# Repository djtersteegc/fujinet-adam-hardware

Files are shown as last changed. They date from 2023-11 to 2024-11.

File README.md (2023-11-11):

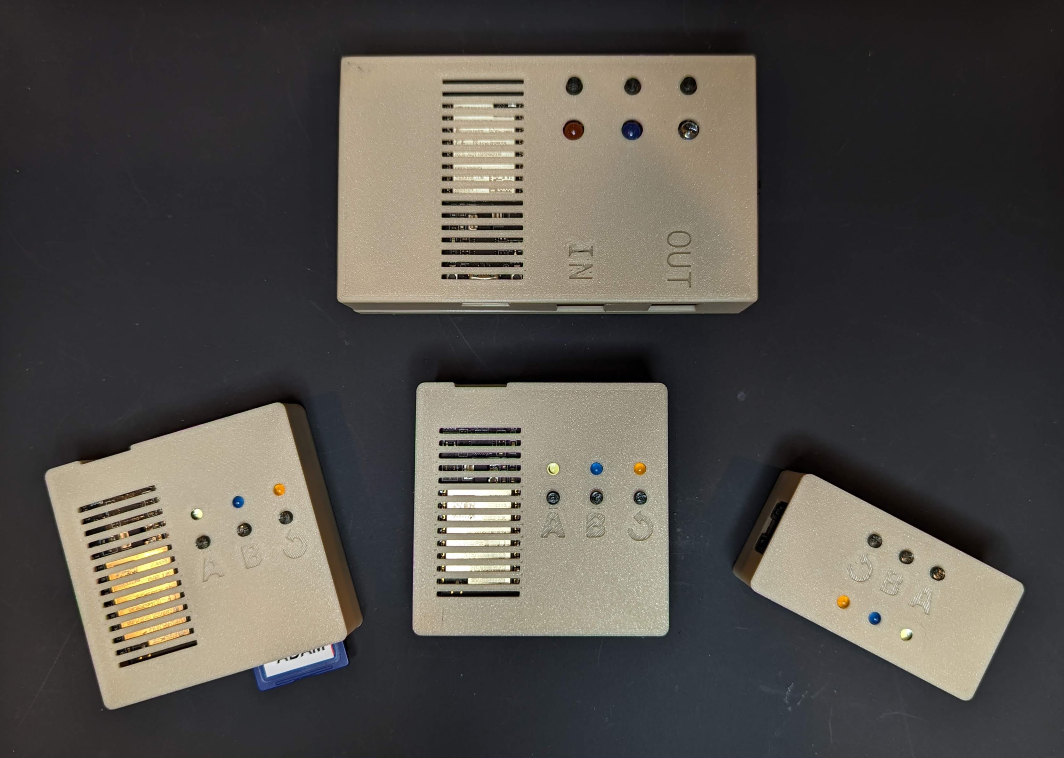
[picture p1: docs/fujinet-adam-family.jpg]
fujinet-adam-family


After building a few of [mozzwald's](https://mozzwald.com/) original [FujiNet](https://fujinet.online/fujinet/) for [Coleco ADAM](https://fujinet.online/fujinet/#ColecoADAM) boards, I decided I wanted to create a new SMD version that was a bit quicker to assemble for folks building them in quantity, but still sticking with the ESP32-Devkit-C-VE board and larger 0805 sized components for the DIY crowd. Both boards are single sided for easy assembly, with the only through hole parts being the RJ12 jack(s), LED's, and the devkit board itself. In the end I ended up with two different designs, one I'm calling the Devkit SMD and the other the Devkit Mini.

# Devkit SMD

Similar to the original design, this one offers two ADAMNet ports to daisy chain other devices, but instead of a microSD slot, now offers a full size SD card.

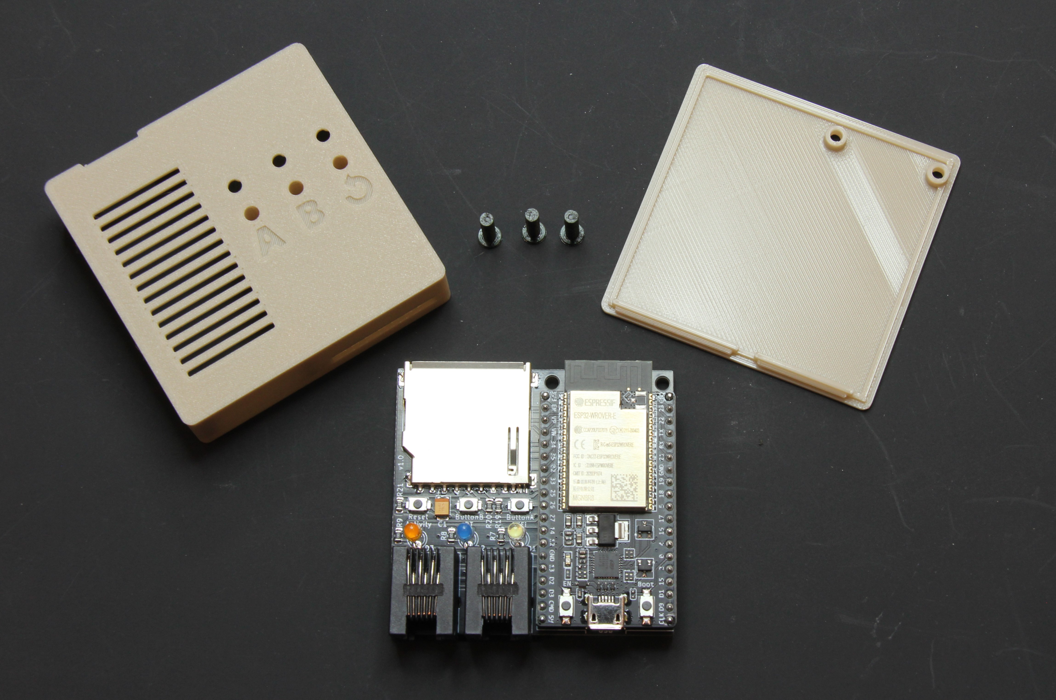
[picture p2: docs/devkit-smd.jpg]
devkit-smd


You can build it in two different configurations, one using 8.5mm female headers for the devkit board, similar to the original.  This gives the options of reusing the ESP32 for something else in the future and easy access to the SMD components underneath it.  If you are confident in your soldering skills and want something more compact, you can also build it with the ESP board soldered directly to the main PCB on 3mm spaces.

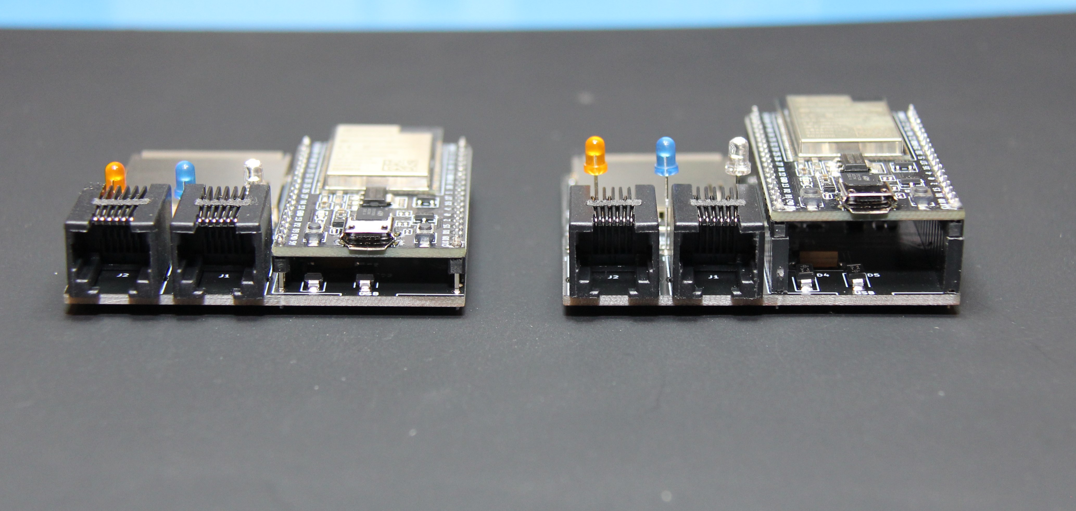
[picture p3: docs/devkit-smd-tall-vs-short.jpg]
devkit-smd-tall-vs-short


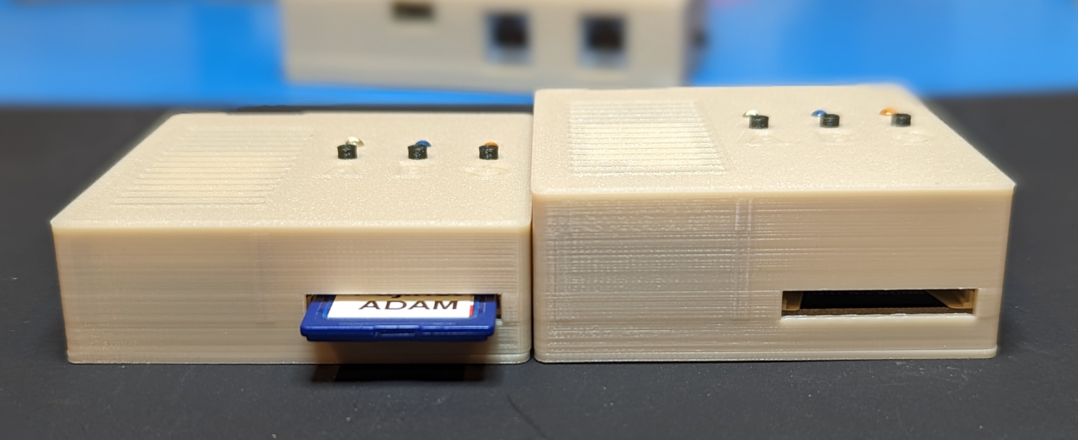
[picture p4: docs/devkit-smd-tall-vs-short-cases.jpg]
devkit-smd-tall-vs-short-cases


See the [Devkit SMD page](fujinet-adam-devkit-smd/README.md) for BOM and assembly instructions.

# Devkit Mini

This was an exercise in can I make a full FujiNet fit in the space of the devkit PCB. For that I had to go back to a microSD slot and it only supports one ADAMNet port.

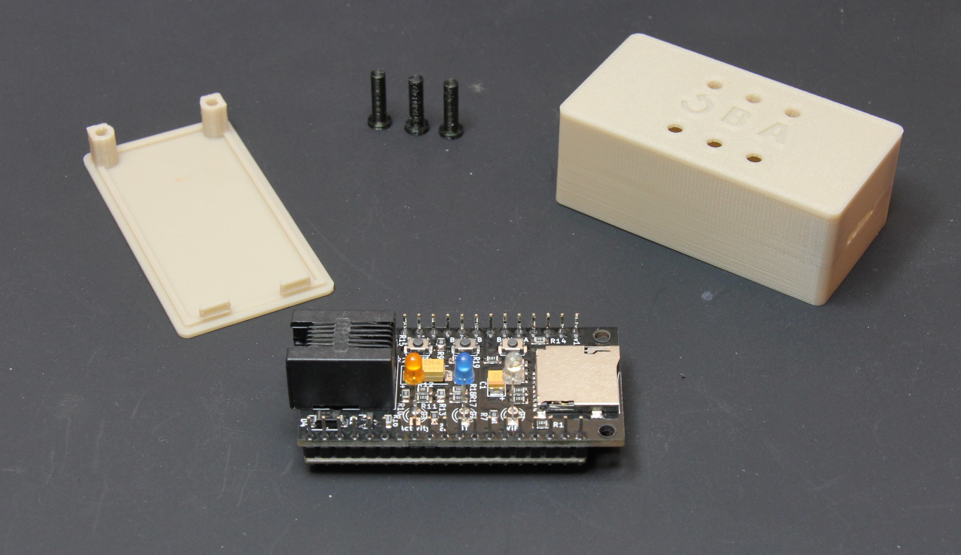
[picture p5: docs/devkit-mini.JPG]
devkit-mini


See the [Devkit Mini page](fujinet-adam-devkit-mini/README.md) for BOM and assembly instructions.

# Getting a Bare Board or Assembled Unit

Any extras I have available will be in my [Tindie](https://www.tindie.com/stores/tersteeg/) store. I don't ship outside the US currently, but gerber files are available for both boards if you want to order your own from your favorite PCB fab like JLCPCB or PCBWay.

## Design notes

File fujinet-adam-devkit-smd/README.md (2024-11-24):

# BOM

There's an interactive BOM [here](https://djtersteegc.github.io/fujinet-adam-hardware/ibom-devkit-smd.html), I find them super useful when placing the SMD parts. 

I buy pretty much everything from AliExpress suppliers with the exception of the tantalum capacitors (whatever is on clearance at Newark) and the ESP32 board (cheaper shipped from Amazon). If you are bulding in the "tall" configuration, you will also need some 2.54mm female headers.  I buy the 1x40p models and break when down into two 19 pin headers required by the devkit board.

C2 is a bulk storage cap for the 5V input from the ADAMNet line.  I speced it at 100uF, but anything from 22uF and up will probably be fine.  You may not even really need it.

C1 is to handle inrush and prevent sag and MCU reboots on the 3.3V rail if you are hot swapping your SD card.  Mozzwald's original design went without, so not strictly needed, especially if you don't plan on hot swapping the card.

| Component | Qty  | Notes | Link |
| --- | ---- | --- | --- |
| 47uF 10V 3528 Tantalum Capacitor | 1 | B Type Case (or smaller) | [AliExpress](https://www.aliexpress.us/item/2251832779546992.html) |
| 100uF 10V 7343 Tantalum Capacitor | 1 | E Type Case (or smaller) | [AliExpress](https://www.aliexpress.us/item/2251832782845246.html) |
| 10K 0805 Resistor | 11 | | [AliExpress](https://www.aliexpress.us/item/3256801607747550.html) |
| 1K 0805 Resistor | 4 | | [AliExpress](https://www.aliexpress.us/item/3256801607747550.html) |
| 2K 0805 Resistor | 2 | | [AliExpress](https://www.aliexpress.us/item/3256801607747550.html) |
| 4.7K 0805 Resistor | 2 | | [AliExpress](https://www.aliexpress.us/item/3256801607747550.html) |
| 1.2K 0805 Resistor | 1 | | [AliExpress](https://www.aliexpress.us/item/3256801607747550.html) |
| 33R 0805 Resistor | 1 | | [AliExpress](https://www.aliexpress.us/item/3256801607747550.html) |
| B140 SMA DO-214 Schottky Diode | 2 | SS14 also works | [AliExpress](https://www.aliexpress.us/item/2255800145156429.html) |
| 3mm LED (Blue) | 1 | Bluetooth | [AliExpress](https://www.aliexpress.us/item/2255800226600744.html) |
| 3mm LED (White) | 1 | Wifi | [AliExpress](https://www.aliexpress.us/item/2255800226600744.html) |
| 3mm LED (Orange) | 1 | Activity | [AliExpress](https://www.aliexpress.us/item/2255800226600744.html) |
| Alps SKRK Style Switch | 3 | 3x4x2mm | [AliExpress](https://www.aliexpress.us/item/2255801131587911.html) |
| MMBT3904 SOT-23 | 1 | | [AliExpress](https://www.aliexpress.us/item/3256802985590487.html) |
| MMBT3906 SOT-23 | 1 | | [AliExpress](https://www.aliexpress.us/item/3256802985563795.html) |
| RJ12 Amphenol 54601 | 2 | 95001-6P6C on Ali | [AliExpress](https://www.aliexpress.us/item/3256802891796239.html) |
| SD Card TE 2041021 | 1 | Long Body on Ali | [AliExpress](https://www.aliexpress.us/item/3256805779248826.html) |
| ESP32-Devkit-C-VE | 1 | | [Amazon](https://www.amazon.com/dp/B087TNPQCV) |
| 2.54mm 19p 8.5mm Tall Female Header | 2 | "Tall" option build only | [AliExpress](https://www.aliexpress.us/item/2251832484668248.html) |
| SK12D07VG4 Slide Switch | 1 | Optional power SW for v1.2 | [AliExpress](https://www.aliexpress.us/item/3256806549741426.html) |

# Flashing

I like to program the ESP32 first to ensure I have a good unit before soldering them onto the main PCB. Since this uses the same devkit board as the "official" model, you can use the FujiNet firmware flasher available at https://fujinet.online/download/. 

# Assembly

Lay down all the SMD components first.  When complete, your board shoud look like this.

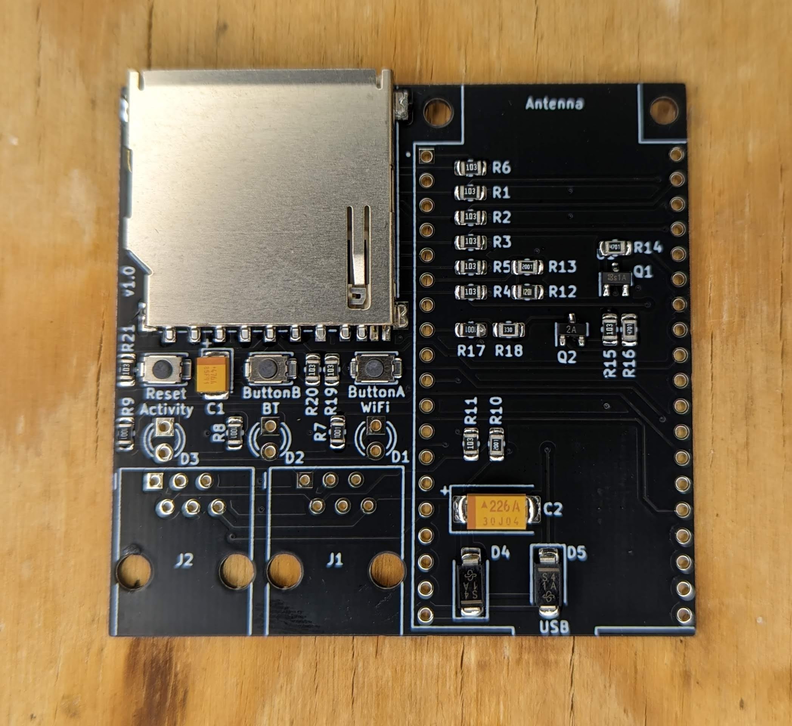
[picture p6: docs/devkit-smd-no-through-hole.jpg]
devkit-smd-no-through-hole


Next decide if you are building it on female headers or soldering the devkit directly to the board.  If the latter, there are some 3mm spacers and support blocks in the "short" 3D directory you can print out to space the devkit board correctly and keep the board level when you flip it over to solder it together.

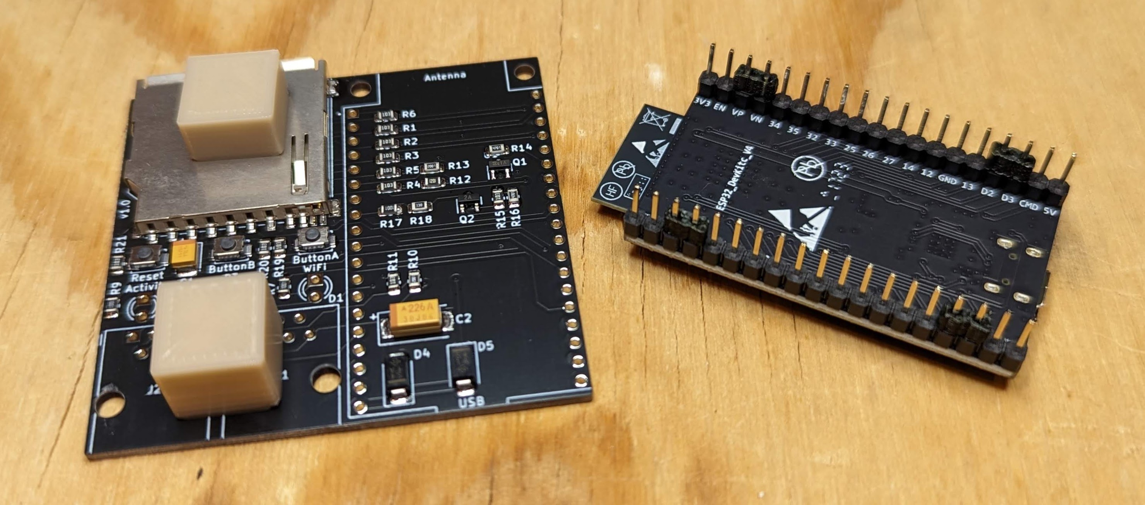
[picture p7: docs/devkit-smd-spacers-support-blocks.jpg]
devkit-smd-spacers-support-blocks


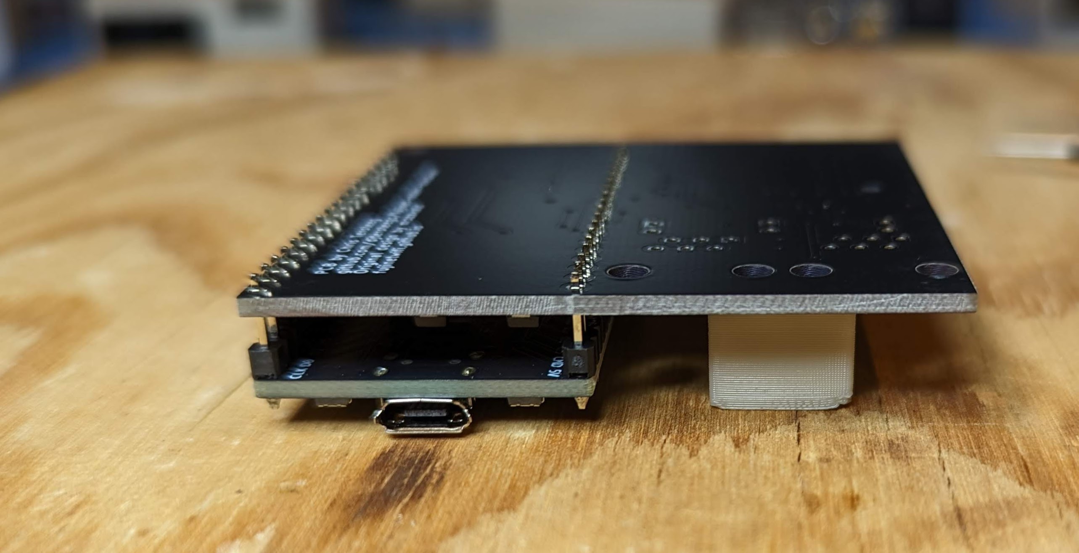
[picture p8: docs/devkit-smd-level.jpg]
devkit-smd-level


Next solder on the two RJ12 jacks.  For the LED's, I first insert them in the PCB, then the PCB in the case, flip it over and support the case ~1mm off the surface for the LED's to just poke through the top and get a nice reveal. Solder one leg on the LED's, flip it over to check your spacing again, and then solder the other leg.

# Case

If built on female headers, print the files in the "tall" directory.  Make sure to print three buttons.  If soldering directly to the board spaced 3mm above it, use the case file in the "short" directory.  Assemble with two M2.5x10mm screws.

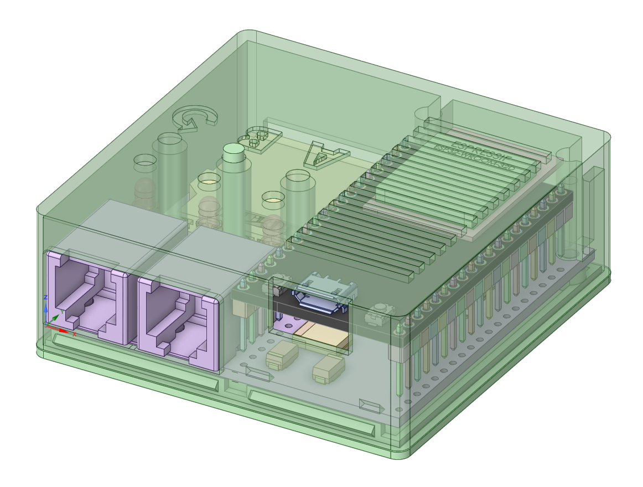
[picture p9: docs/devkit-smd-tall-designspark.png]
devkit-smd-tall-designspark


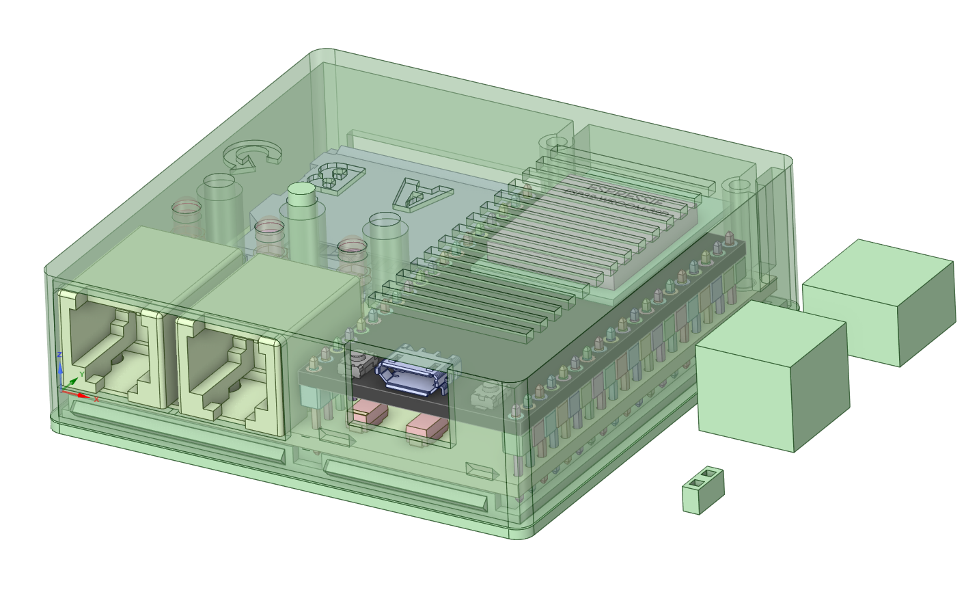
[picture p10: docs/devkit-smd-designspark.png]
devkit-smd-designspark


PCB version 1.2 adds the ability to install a power switch if you want to disable the Fuji in your ADAMNet chain without unplugging it.

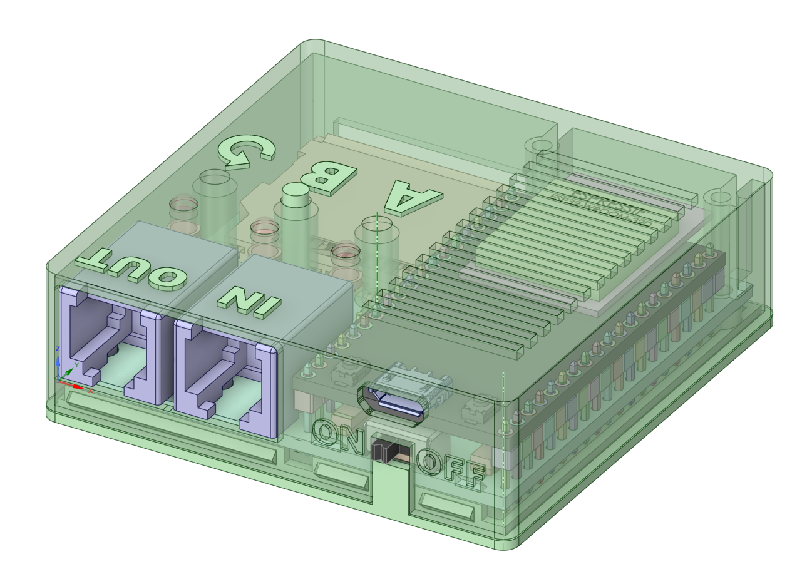
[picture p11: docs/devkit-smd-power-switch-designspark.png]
devkit-smd-power-switch-designspark


If you are printing with a multi color AMS enabled printer, you can use the embossed-text STL files to color fill the top text.

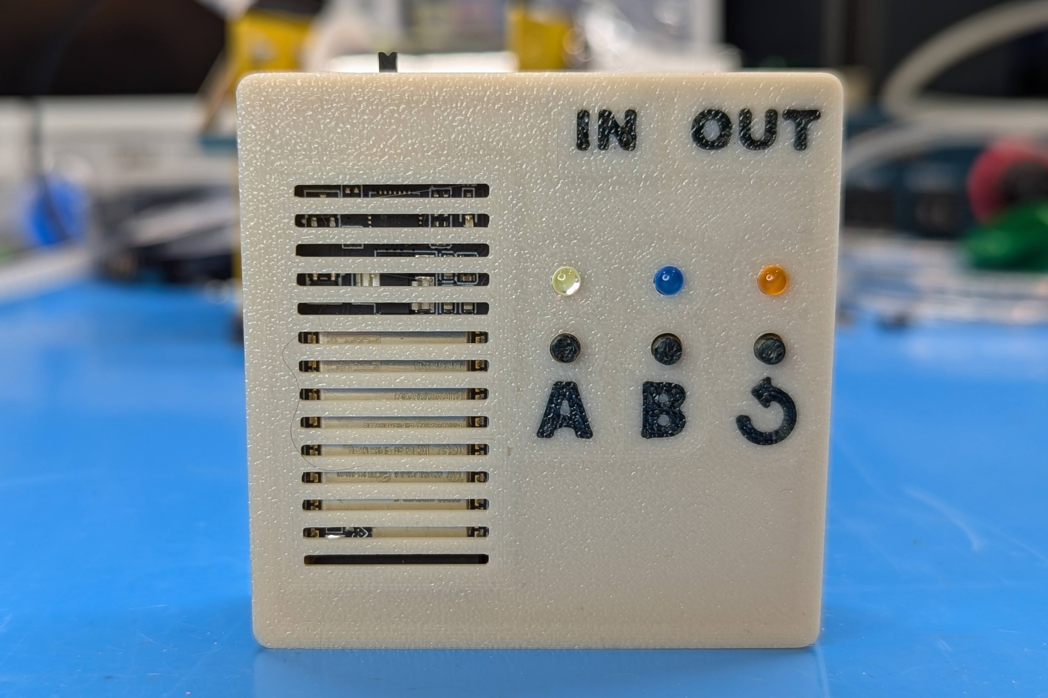
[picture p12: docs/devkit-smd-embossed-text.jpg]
devkit-smd-embossed-text


# PCB Revisions

### Version 1.0

Working, but the second RJ12/ADAMNet connector was incorrectly wired in the schematic and does not work as intended.  I assumed straight through when it should have been reversed, hence the RJ12 cross over cables used on the ADAM. Fortunately, the fix is pretty simple and by luck of the ground planes, you don't even need to remove the RJ12 connector.

These the PCB traces you need to cut (black X's).

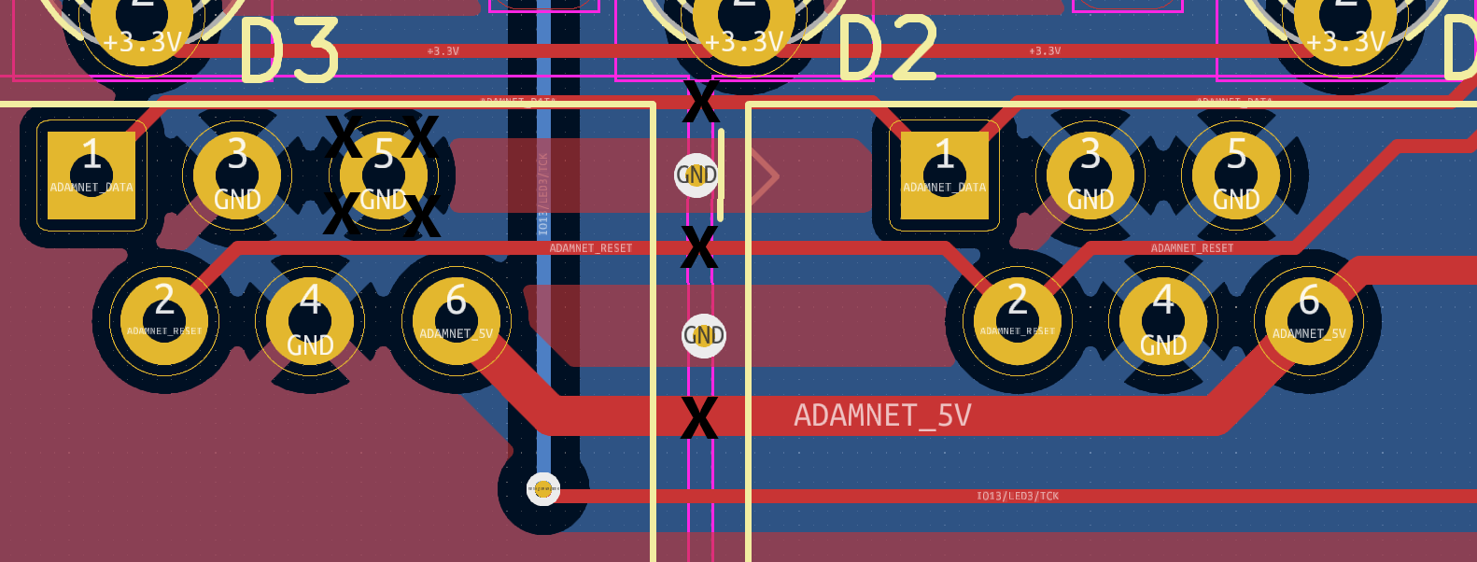
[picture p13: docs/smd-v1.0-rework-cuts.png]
smd-v1.0-rework-cuts


Three are on the top between the two RJ12 jacks.  I used an Xacto blade. Be careful of the trace immediately above the top one connecting the 3.3V rail of the LED's.  I nicked the one in this example, but it was still connected.  Worst case, you need to add another wire to bodge D2 to D3.

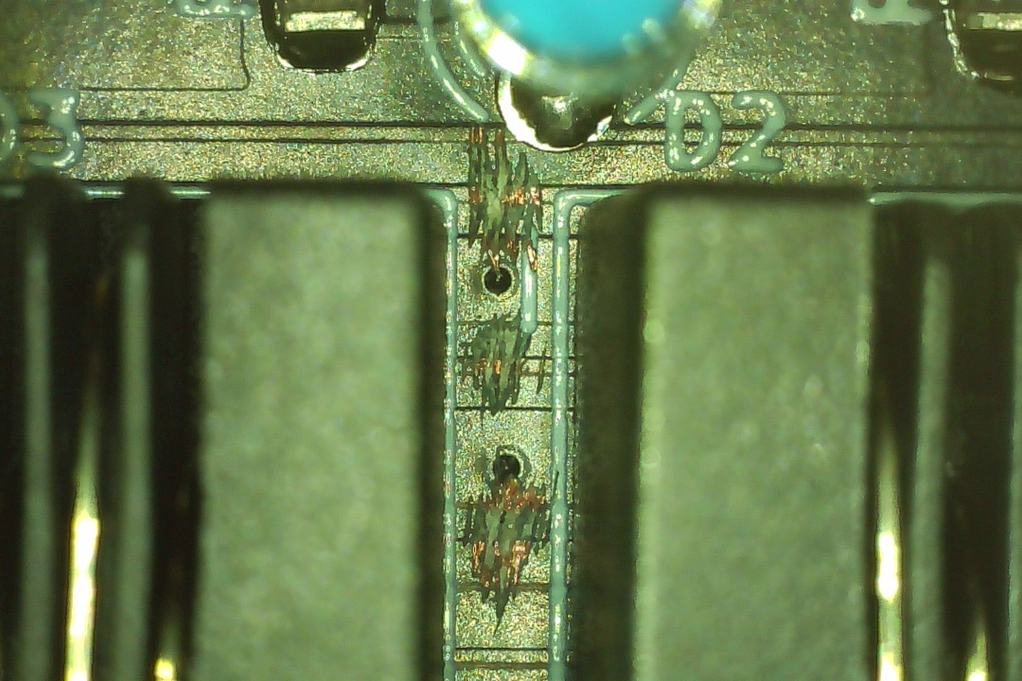
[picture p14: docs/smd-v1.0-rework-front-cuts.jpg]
smd-v1.0-rework-front-cuts


Then you need to seperate the Pin 5 (lower right in the photo) on the back from the four ground plane thermal relief connections.

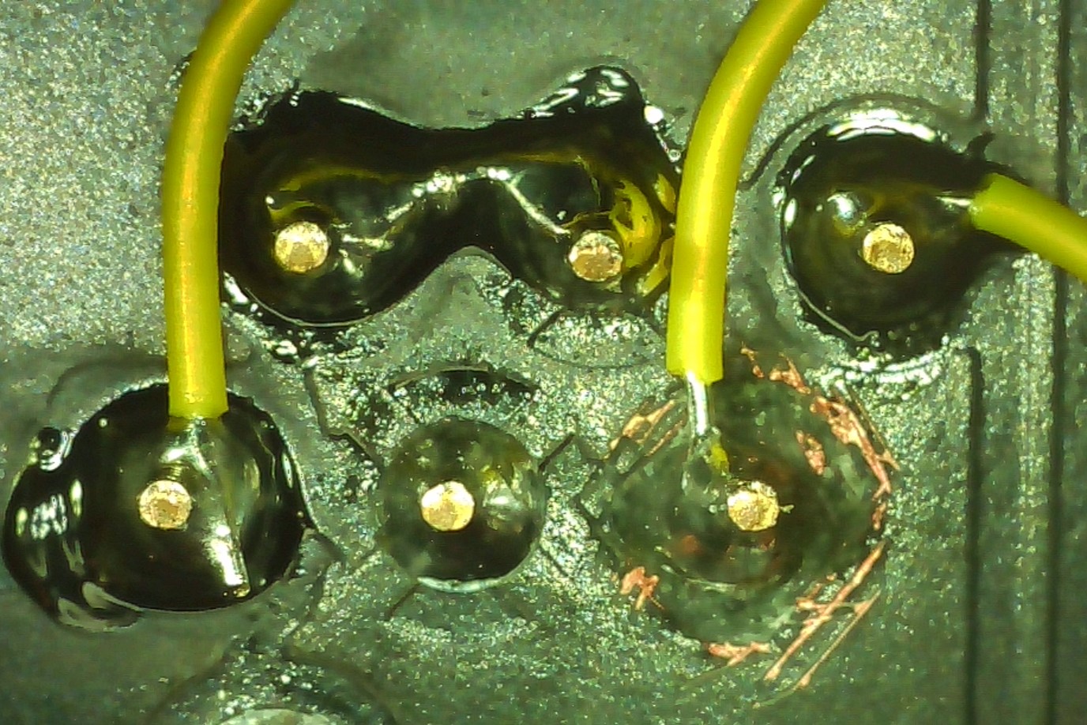
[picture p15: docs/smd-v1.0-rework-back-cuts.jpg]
smd-v1.0-rework-back-cuts


Finally you need to connect J2 to the correct pins on J1. 

| J1 - ADAMNet In | J2 - ADAMNet Out |
| --- | --- |
| 1 (Data) | 6 (Data) |
| 2 (Reset) | 5 (Reset) |
| 3 (GND) | 4 (GND) |
| 4 (GND) | 3 (GND) |
| 5 (GND) | 2 (GND) |
| 6 (5V) | 1 (5V) |

Since pin 3 and pin 4 on J2 are alreay connected to ground nothing to do there.  You can connect Pin 2 which is now GND to Pin 4.  The remaining three pins need bodge wires over to J1.  Here's what it should look like completed.

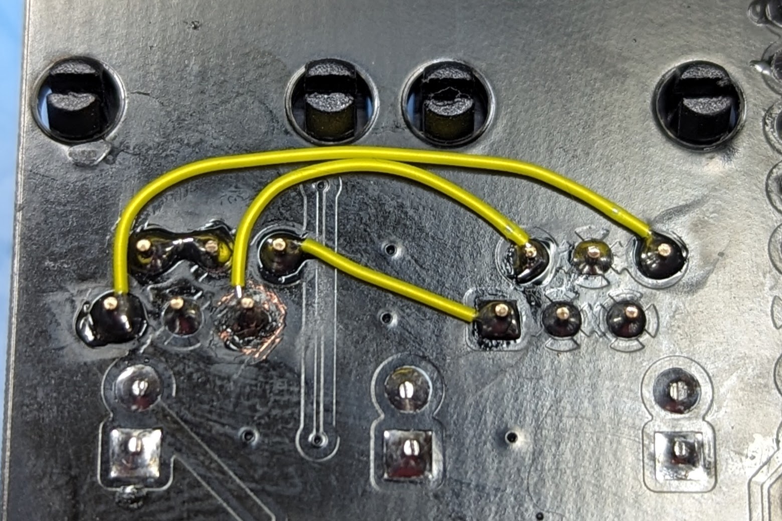
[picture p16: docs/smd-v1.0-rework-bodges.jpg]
smd-v1.0-rework-bodges


Check the connections from J1 to J2 and ensure the 5V line in particular it not shorted to GND.  Plug into the Adam to confirm all is now working with the keyboard plugged into the AdamNET Out (left most) port on the Fujinet.

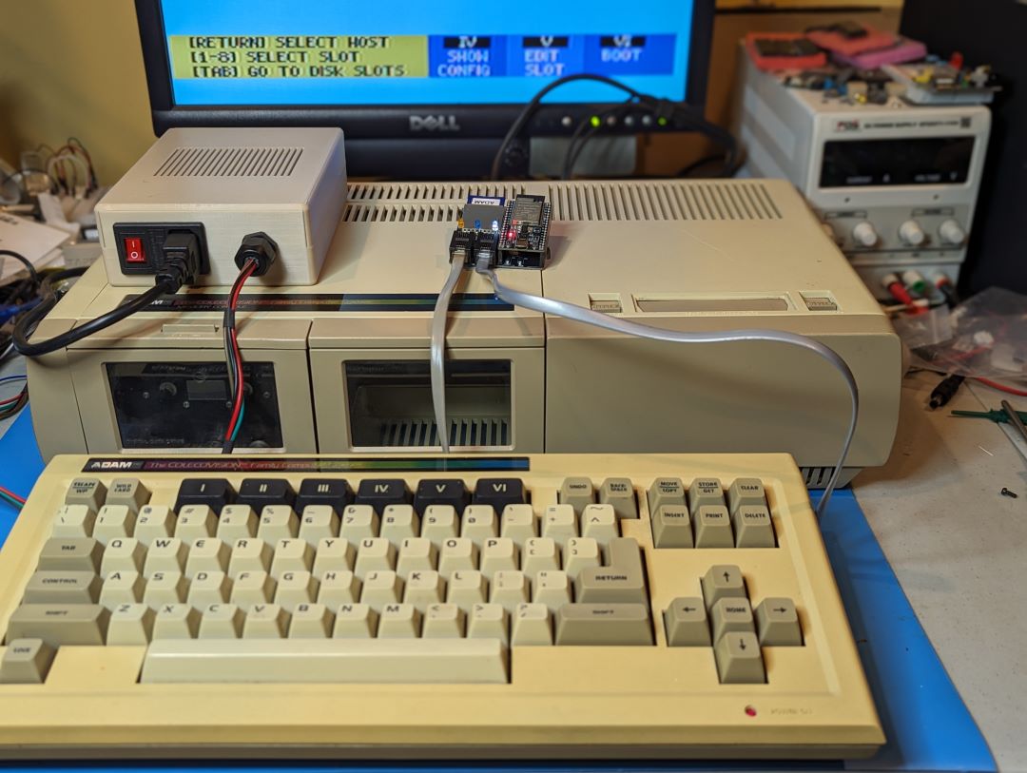
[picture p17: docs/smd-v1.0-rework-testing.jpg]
smd-v1.0-rework-testing


### Version 1.1

All good

### Version 1.2

Adds an optional power switch.  If you don't want to install the swtich, bridge the Always On solder jumper.

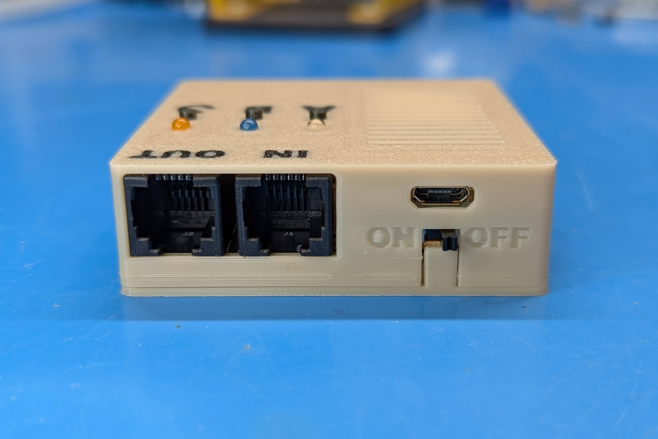
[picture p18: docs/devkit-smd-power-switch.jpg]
devkit-smd-power-switch


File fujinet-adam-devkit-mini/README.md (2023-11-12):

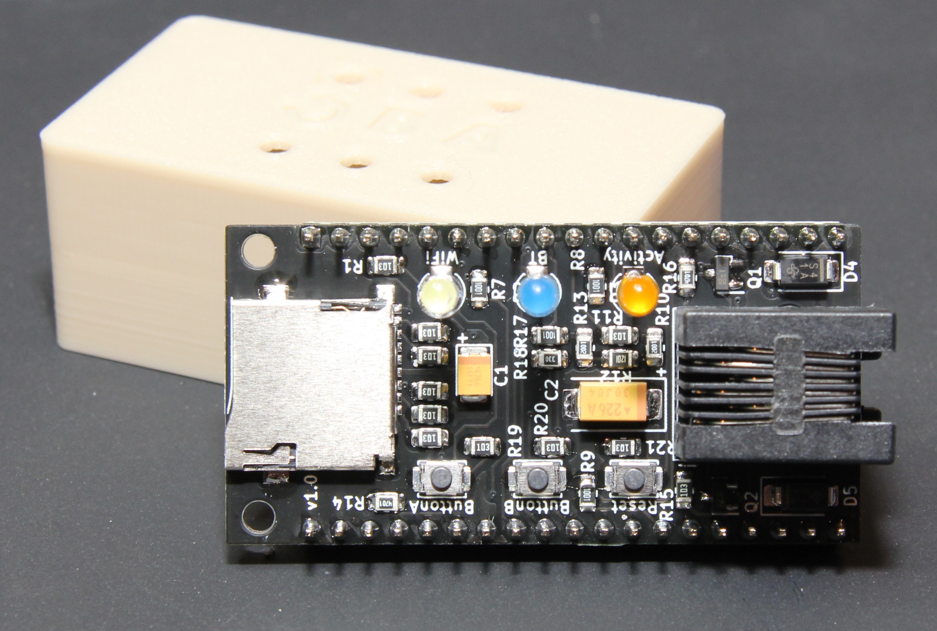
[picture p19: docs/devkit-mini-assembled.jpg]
devkit-mini-assembled


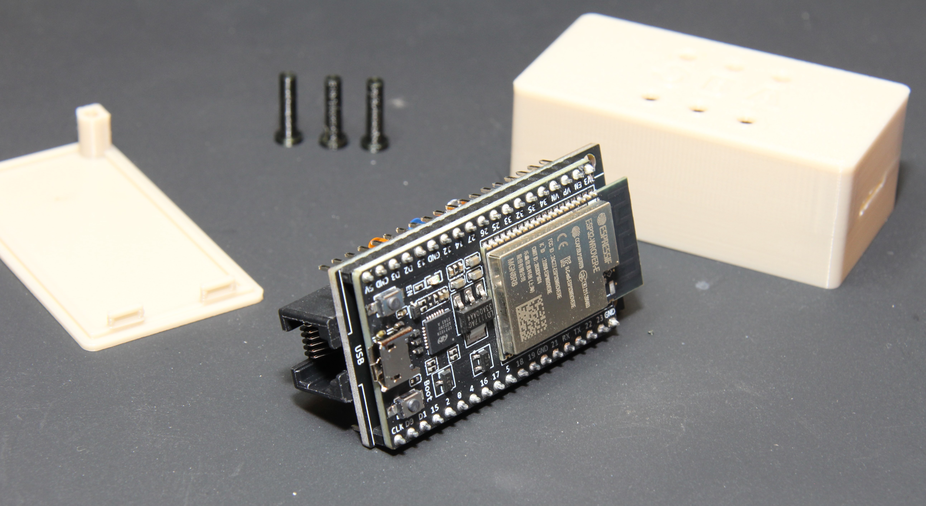
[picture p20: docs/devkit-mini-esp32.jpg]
devkit-mini-esp32


# BOM

There's an interactive BOM [here](https://djtersteegc.github.io/fujinet-adam-hardware/ibom-devkit-mini.html), I find them super useful when placing the SMD parts. 

I buy pretty much everthing from AliExpress suppliers with the exception of the tantalum capacitors (whatever is on clearance at Newark) and the ESP32 board (cheaper shipped from Amazon).

C2 is a bulk storage cap for the 5V input from the ADAMNet line.  I speced it at 100uF, but anything from 22uF and up will probably be fine.  You may not even really need it.

C1 is to handle inrush and prevent sag and MCU reboots on the 3.3V rail if you are hot swapping your SD card.  Mozzwald's original design went without, so not strictly needed, especially if you don't plan on hot swapping the card.

| Component | Qty  | Notes | Link |
| --- | ---- | --- | --- |
| 47uF 10V 3528 Tantalum Capacitor  | 1 | B Type Case (or smaller) | [AliExpress](https://www.aliexpress.us/item/2251832779546992.html) |
| 100uF 10V 7343 Tantalum Capacitor | 1 | E Type Case (or smaller) | [AliExpress](https://www.aliexpress.us/item/2251832782845246.html) |
| 10K 0805 Resistor | 11 | | [AliExpress](https://www.aliexpress.us/item/3256801607747550.html) |
| 1K 0805 Resistor | 4 | | [AliExpress](https://www.aliexpress.us/item/3256801607747550.html) |
| 2K 0805 Resistor | 2 | | [AliExpress](https://www.aliexpress.us/item/3256801607747550.html) |
| 4.7K 0805 Resistor | 2 | | [AliExpress](https://www.aliexpress.us/item/3256801607747550.html) |
| 1.2K 0805 Resistor | 1 | | [AliExpress](https://www.aliexpress.us/item/3256801607747550.html) |
| 33R 0805 Resistor | 1 | | [AliExpress](https://www.aliexpress.us/item/3256801607747550.html) |
| B140 SMA DO-214 Schottky Diode | 2 | SS14 also works | [AliExpress](https://www.aliexpress.us/item/2255800145156429.html) |
| 3mm LED (Blue) | 1 | Bluetooth | [AliExpress](https://www.aliexpress.us/item/2255800226600744.html) |
| 3mm LED (White) | 1 | Wifi | [AliExpress](https://www.aliexpress.us/item/2255800226600744.html) |
| 3mm LED (Orange) | 1 | Activity | [AliExpress](https://www.aliexpress.us/item/2255800226600744.html) |
| Alps SKRK Style Switch | 3 | 3x4x2mm | [AliExpress](https://www.aliexpress.us/item/2255801131587911.html) |
| MMBT3904 SOT-23 | 1 | | [AliExpress](https://www.aliexpress.us/item/3256802985590487.html) |
| MMBT3906 SOT-23 | 1 | | [AliExpress](https://www.aliexpress.us/item/3256802985563795.html) |
| RJ12 Amphenol 54601 | 1 | 95001-6P6C on Ali | [AliExpress](https://www.aliexpress.us/item/3256802891796239.html) |
| microSD Socket | 1 | Push-Push TransFlash on Ali | [AliExpress](https://www.aliexpress.us/item/2251832615736950.html) |
| ESP32-Devkit-C-VE | 1 | | [Amazon](https://www.amazon.com/dp/B087TNPQCV) |

# Flashing

I like to program the ESP32 first to ensure I have a good unit before soldering them onto the main PCB. Since this uses the same devkit board as the "official" model, you can use the FujiNet firmware flasher available at https://fujinet.online/download/. 

# Assembly

Lay down all the SMD components first.

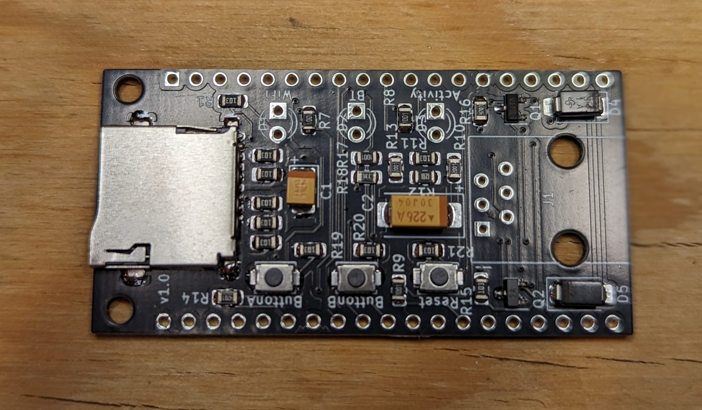
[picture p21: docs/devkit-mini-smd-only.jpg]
devkit-mini-smd-only
 

Next solder on the RJ12 jack.  For the LED's, I first insert them in the PCB, then the PCB in the case, flip it over and support the case ~1mm off the surface (laying the case across the lip of the lid works well for this) for the LED's to just poke through the top and get a nice reveal. Solder one leg on the LED's, flip it over to check your spacing again, and then solder the other leg.

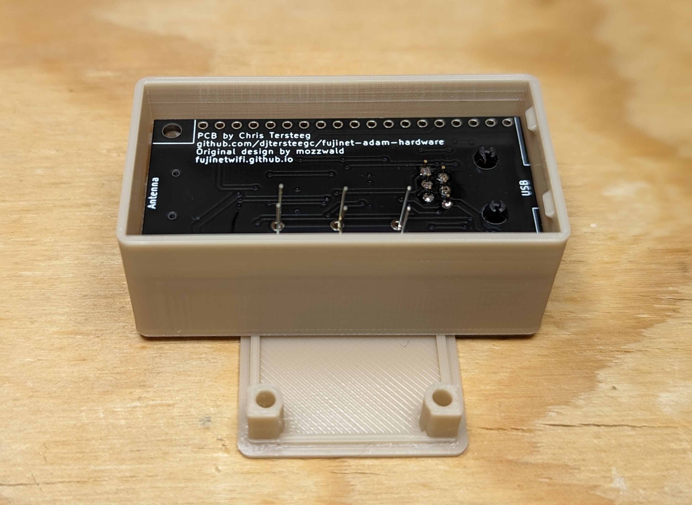
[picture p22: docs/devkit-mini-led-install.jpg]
devkit-mini-led-install


Finally, solder on the devkit board.  I found the cheap PCB/phone vises work well for holding the main PCB while you do this.

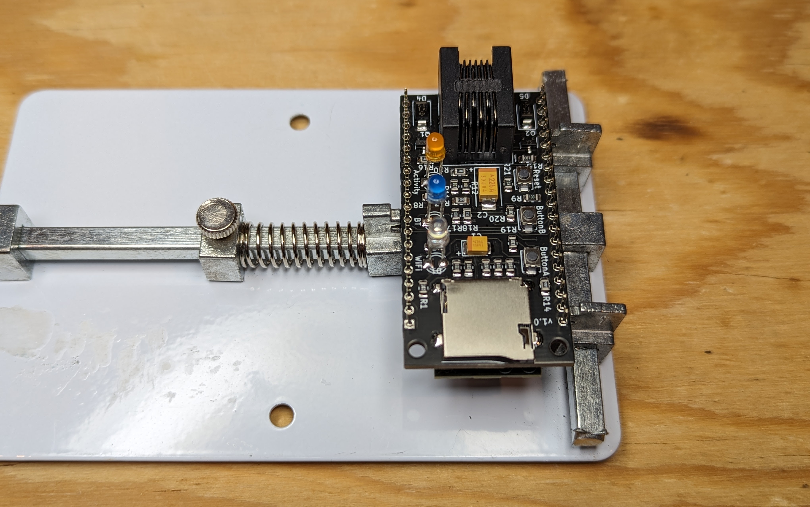
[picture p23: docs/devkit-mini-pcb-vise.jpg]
devkit-mini-pcb-vise


# Case

Make sure to print three buttons.  Assemble with two M2.5x16mm screws.

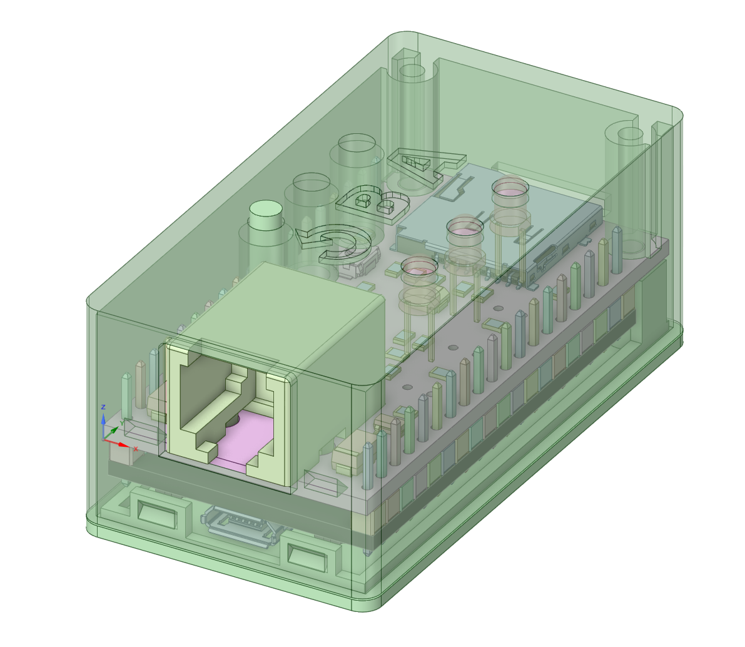
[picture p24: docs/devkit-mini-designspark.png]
devkit-mini-designspark


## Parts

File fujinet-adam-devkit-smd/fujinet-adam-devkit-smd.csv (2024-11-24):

Reference | Value | Datasheet | Footprint | Qty | DNP
C1 | 47uF 10v | ~ | Capacitor_Tantalum_SMD:CP_EIA-3528-15_AVX-H_Pad1.50x2.35mm_HandSolder | 1
C2 | 100uF 10V | ~ | Capacitor_Tantalum_SMD:CP_EIA-7343-20_Kemet-V_Pad2.25x2.55mm_HandSolder | 1
D1 | WIFI_WHITE | ~ | LED_THT:LED_D3.0mm | 1
D2 | BT_BLUE | ~ | LED_THT:LED_D3.0mm | 1
D3 | BUS_ORANGE | ~ | LED_THT:LED_D3.0mm | 1
D4,D5 | B140-E3 | http://www.vishay.com/docs/88946/b120.pdf | Diode_SMD:D_SMA | 2
H1,H2 | MountingHole | ~ | MountingHole:MountingHole_2.7mm_M2.5 | 2
J1 | In | ~ | Connector_RJ:RJ12_Amphenol_54601 | 1
J2 | Out | ~ | Connector_RJ:RJ12_Amphenol_54601 | 1
J3 | SD_Card | http://portal.fciconnect.com/Comergent//fci/drawing/10067847.pdf | Connector_Card:SD_TE_2041021 | 1
JP1 | Always On | ~ | Jumper:SolderJumper-2_P1.3mm_Open_RoundedPad1.0x1.5mm | 1
Q1 | MMBT3904 | https://www.onsemi.com/pdf/datasheet/pzt3904-d.pdf | Package_TO_SOT_SMD:SOT-23 | 1
Q2 | MMBT3906 | https://www.onsemi.com/pdf/datasheet/pzt3906-d.pdf | Package_TO_SOT_SMD:SOT-23 | 1
R1,R2,R3,R4,R5,R6,R11,R15,R19,R20,R21 | 10K | ~ | Resistor_SMD:R_0805_2012Metric_Pad1.20x1.40mm_HandSolder | 11
R7,R8,R9,R17 | 1K | ~ | Resistor_SMD:R_0805_2012Metric_Pad1.20x1.40mm_HandSolder | 4
R10,R13 | 2K | ~ | Resistor_SMD:R_0805_2012Metric_Pad1.20x1.40mm_HandSolder | 2
R12 | 1.2K | ~ | Resistor_SMD:R_0805_2012Metric_Pad1.20x1.40mm_HandSolder | 1
R14,R16 | 4.7K | ~ | Resistor_SMD:R_0805_2012Metric_Pad1.20x1.40mm_HandSolder | 2
R18 | 33R | ~ | Resistor_SMD:R_0805_2012Metric_Pad1.20x1.40mm_HandSolder | 1
S1 | SK12D07VG4 |  | SK12D07VG4:SK12D07VG4 | 1
SW1 | ButtonA | ~ | Button_Switch_SMD:SW_Push_SPST_NO_Alps_SKRK | 1
SW2 | ButtonB | ~ | Button_Switch_SMD:SW_Push_SPST_NO_Alps_SKRK | 1
SW3 | Safe Reset | ~ | Button_Switch_SMD:SW_Push_SPST_NO_Alps_SKRK | 1
U1 | ESP32-DevKitC-VE |  | ESP32-DEVKITC-32U:MODULE_ESP32-DEVKITC-32U | 1

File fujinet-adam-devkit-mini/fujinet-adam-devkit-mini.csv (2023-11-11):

# | Reference | Qty | Value | Footprint | DNP
1 | C1 | 1 | 47uF 10v | Capacitor_Tantalum_SMD:CP_EIA-3528-15_AVX-H_Pad1.50x2.35mm_HandSolder
2 | C2 | 1 | 100uF 10V | Capacitor_Tantalum_SMD:CP_EIA-7343-20_Kemet-V_Pad2.25x2.55mm_HandSolder
3 | D1 | 1 | WIFI_WHITE | LED_THT:LED_D3.0mm
4 | D2 | 1 | BT_BLUE | LED_THT:LED_D3.0mm
5 | D3 | 1 | BUS_ORANGE | LED_THT:LED_D3.0mm
6 | D4, D5 | 2 | B140-E3 | Diode_SMD:D_SMA
7 | H1, H2 | 2 | MountingHole | MountingHole:MountingHole_2.7mm_M2.5
8 | J1 | 1 | RJ12 | Connector_RJ:RJ12_Amphenol_54601
9 | P1 | 1 | ST-TF-003A | ST-TF-003A:SUNTECH_ST-TF-003A
10 | Q1 | 1 | MMBT3904 | Package_TO_SOT_SMD:SOT-23
11 | Q2 | 1 | MMBT3906 | Package_TO_SOT_SMD:SOT-23
12 | R1, R2, R3, R4, R5, R6, R11, R15, R19, R20, R21 | 11 | 10K | Resistor_SMD:R_0805_2012Metric_Pad1.20x1.40mm_HandSolder
13 | R7, R8, R9, R17 | 4 | 1K | Resistor_SMD:R_0805_2012Metric_Pad1.20x1.40mm_HandSolder
14 | R10, R13 | 2 | 2K | Resistor_SMD:R_0805_2012Metric_Pad1.20x1.40mm_HandSolder
15 | R12 | 1 | 1.2K | Resistor_SMD:R_0805_2012Metric_Pad1.20x1.40mm_HandSolder
16 | R14, R16 | 2 | 4.7K | Resistor_SMD:R_0805_2012Metric_Pad1.20x1.40mm_HandSolder
17 | R18 | 1 | 33R | Resistor_SMD:R_0805_2012Metric_Pad1.20x1.40mm_HandSolder
18 | SW1 | 1 | ButtonA | Button_Switch_SMD:SW_Push_SPST_NO_Alps_SKRK
19 | SW2 | 1 | ButtonB | Button_Switch_SMD:SW_Push_SPST_NO_Alps_SKRK
20 | SW3 | 1 | Safe Reset | Button_Switch_SMD:SW_Push_SPST_NO_Alps_SKRK
21 | U1 | 1 | ESP32-DevKitC-VE | ESP32-DEVKITC-32U:MODULE_ESP32-DEVKITC-32U

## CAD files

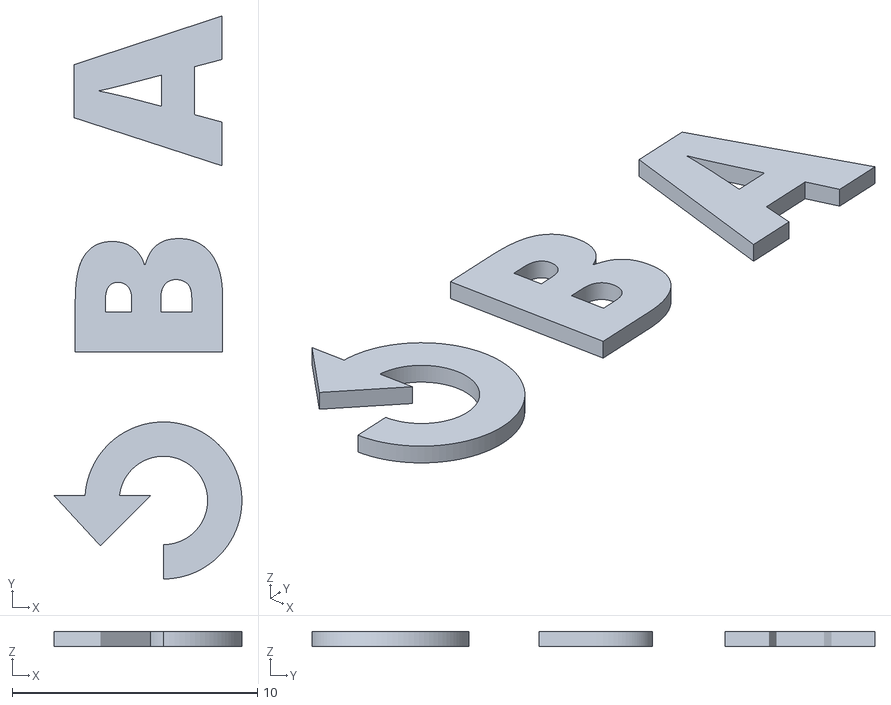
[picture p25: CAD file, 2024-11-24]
fujinet-adam-devkit-mini/3D/fujinet-adam-devkit-mini-embossed-text.stl
7.66 x 22.9 x 0.6

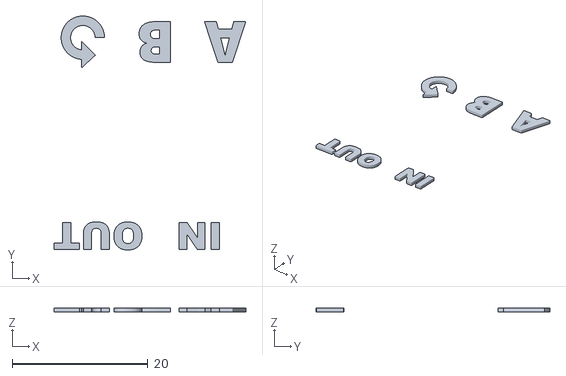
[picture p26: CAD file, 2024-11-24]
fujinet-adam-devkit-smd/3D/short-power-switch/fujinet-adam-devkit-smd-short-power-switch-embossed-text.stl
28.2 x 34.5 x 0.6

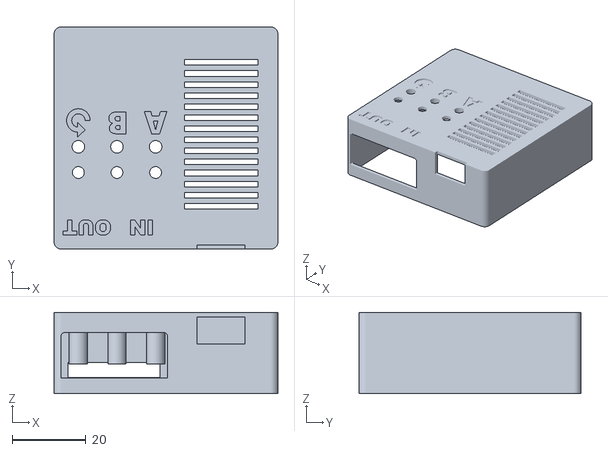
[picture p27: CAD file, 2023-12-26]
fujinet-adam-devkit-smd/3D/tall/fujinet-adam-devkit-smd-case.stl
60.8 x 60.3 x 22.0

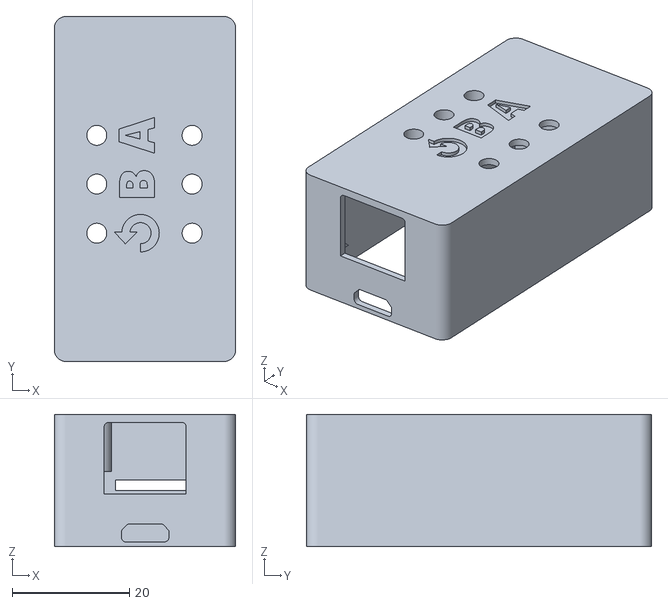
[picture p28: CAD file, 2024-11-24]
fujinet-adam-devkit-mini/3D/fujinet-adam-devkit-mini-body.stl
30.9 x 58.8 x 22.6

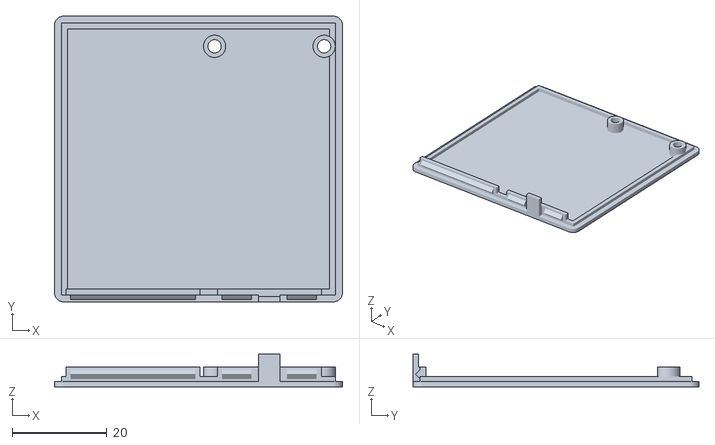
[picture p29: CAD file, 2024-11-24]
fujinet-adam-devkit-smd/3D/short-power-switch/fujinet-adam-devkit-smd-short-power-switch-lid.stl
60.8 x 60.3 x 6.95

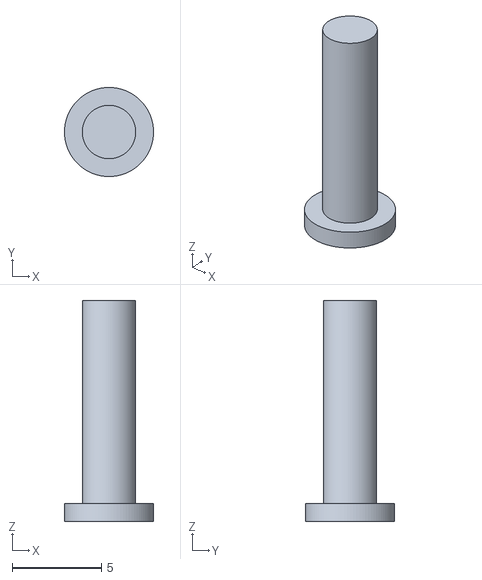
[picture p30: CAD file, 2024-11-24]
fujinet-adam-devkit-smd/3D/short/fujinet-adam-devkit-smd-button.stl
5.00 x 5.00 x 12.4

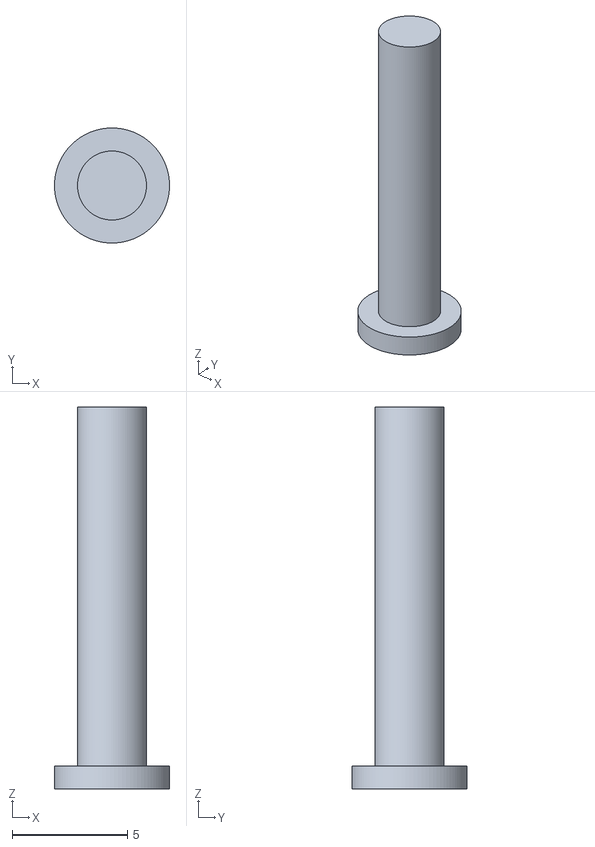
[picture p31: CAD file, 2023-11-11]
fujinet-adam-devkit-smd/3D/tall/fujinet-adam-devkit-smd-button.stl
5.00 x 5.00 x 16.6

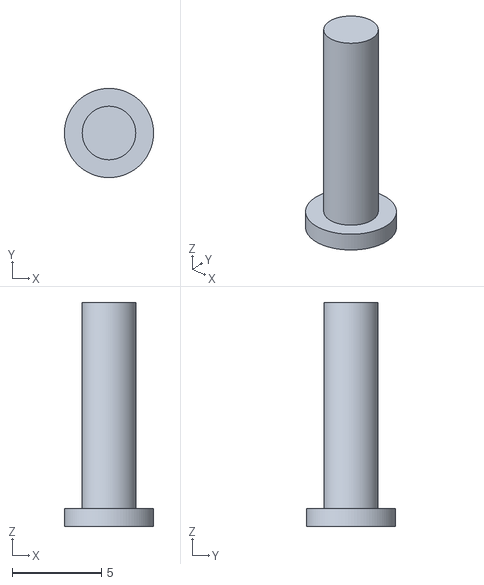
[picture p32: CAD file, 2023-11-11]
fujinet-adam-devkit-mini/3D/fujinet-adam-devkit-mini-button.stl
5.00 x 5.00 x 12.6

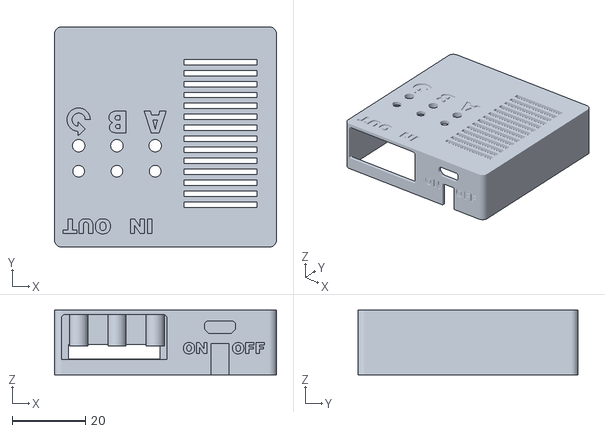
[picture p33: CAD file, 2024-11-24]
fujinet-adam-devkit-smd/3D/short-power-switch/fujinet-adam-devkit-smd-short-power-switch-case.stl
60.8 x 60.3 x 17.8

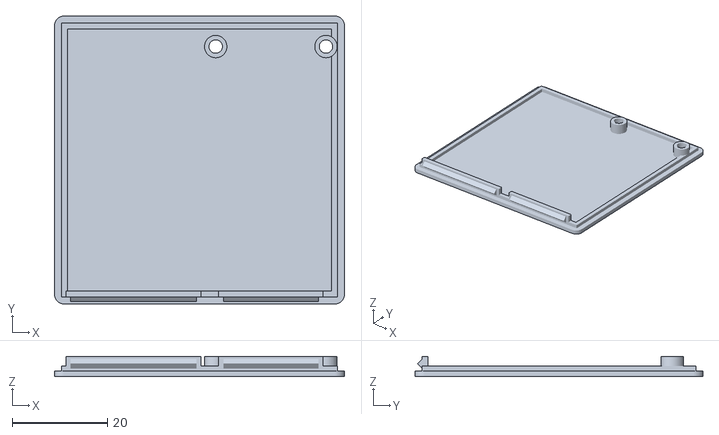
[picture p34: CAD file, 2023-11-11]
fujinet-adam-devkit-smd/3D/tall/fujinet-adam-devkit-smd-lid.stl
60.8 x 60.3 x 4.20

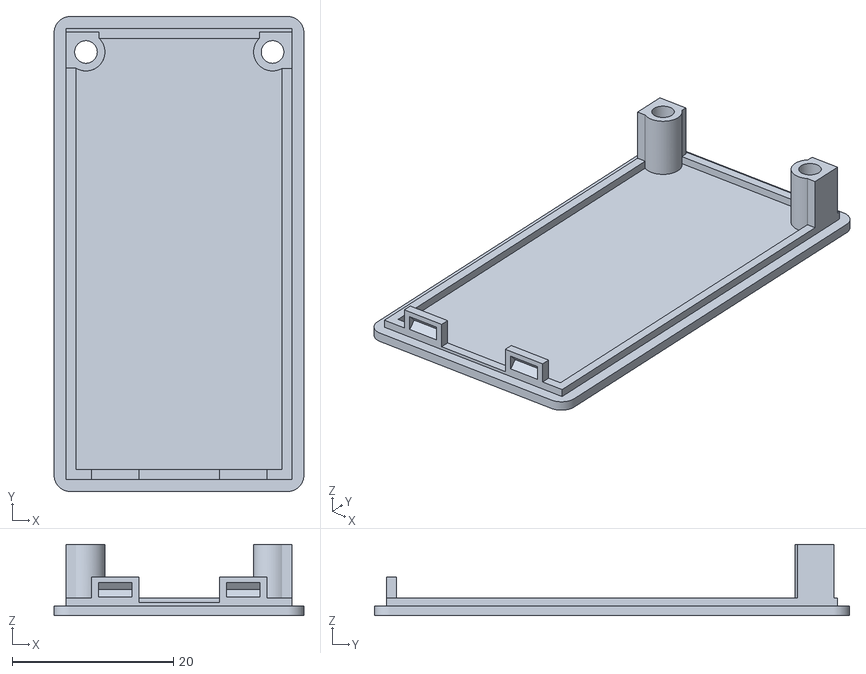
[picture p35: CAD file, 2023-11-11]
fujinet-adam-devkit-mini/3D/fujinet-adam-devkit-mini-lid.stl
30.9 x 58.8 x 8.80

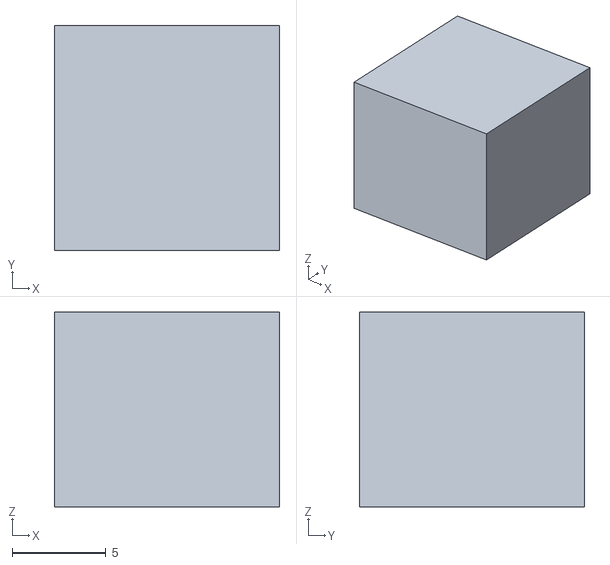
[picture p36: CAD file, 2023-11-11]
fujinet-adam-devkit-smd/3D/short/fujinet-adam-devkit-smd-10.4mm-build-support.stl
12.0 x 12.0 x 10.4

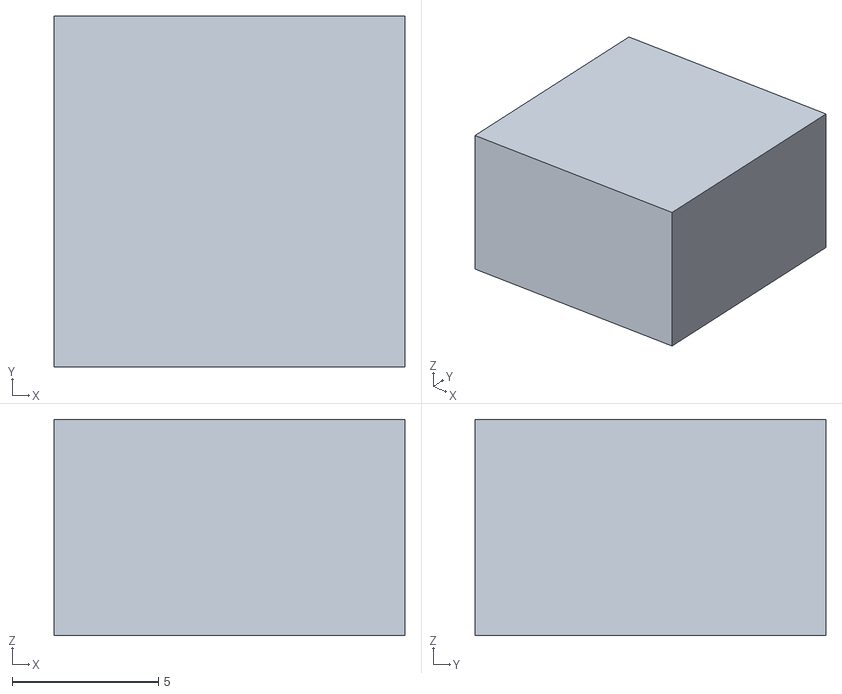
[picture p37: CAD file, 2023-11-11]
fujinet-adam-devkit-smd/3D/short/fujinet-adam-devkit-smd-7.4mm-build-support.stl
12.0 x 12.0 x 7.40

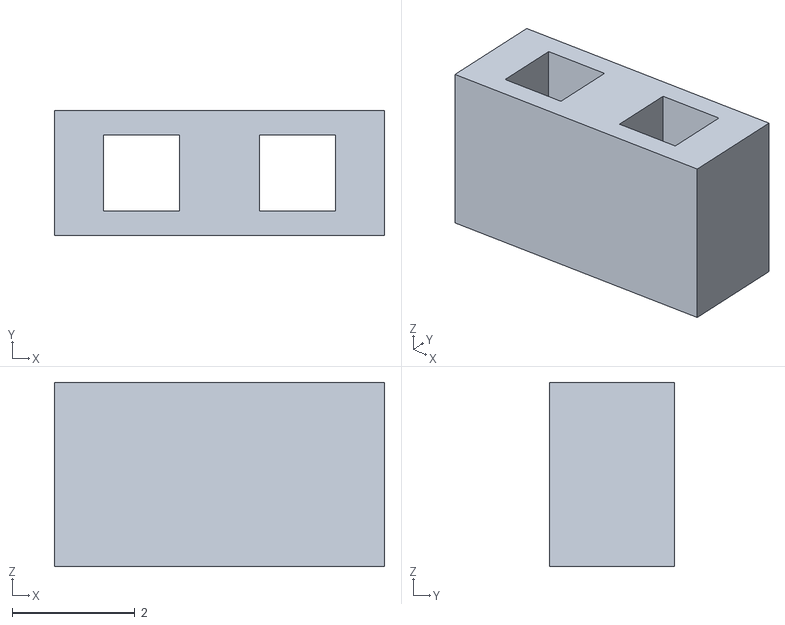
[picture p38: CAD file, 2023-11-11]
fujinet-adam-devkit-smd/3D/short/fujinet-adam-devkit-smd-3mm-spacer.stl
5.38 x 2.04 x 3.00

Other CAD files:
fujinet-adam-devkit-smd/3D/short/fujinet-adam-devkit-smd-embossed-text.stl
fujinet-adam-devkit-smd/3D/short/fujinet-adam-devkit-smd-case.stl
fujinet-adam-devkit-smd/3D/short/fujinet-adam-devkit-smd-lid.stl

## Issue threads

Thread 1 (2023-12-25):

Keyboard conflicts with FujiNet

tingtron, 2023-12-25:
FujiNet and Keyboard connected at the same time have some sort of conflict:
When they keyboard is connected to FujiNet OUT, then

1. There is no keyboard light and keyboard does not type, and
2. Adam-reset always goes to the Typewriter mode, so FujiNet is not activated and only shows an internal red light

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

Separately the keyboard and FujiNet seem to work:
- Fujinet without keyboard, after Adam Reset, boots and shows the Wifi selection screen
- Keyboard by itself is working fine: keyboard light is on, Adam enters Typewriter mode, and types away on the screen.

tingtron, 2023-12-25:
I didn’t find in any guides or videos how exactly FujiNet and the keyboard are connected.
Only in the last [4-hour video](https://youtu.be/P4H7T_FuuqI?si=KzDoaSyd_7JOGv4V&t=1033) I saw that there is another port hidden under on the left side.

But it is still a valid question: how come the pass-through does not work?
Maybe it has to do with the cross over nature of the cable.

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

djtersteegc, 2023-12-26:
Port was incorrectly wired on the schematic.  Added rework instructions for V1.0 here, https://github.com/djtersteegc/fujinet-adam-hardware/tree/main/fujinet-adam-devkit-smd.  Will correct in a V1.1 PCB moving forward.  Will leave issue open until confirm fixed in next PCB revision.

tingtron, 2023-12-26:
So it looks like in V1.0 the connectors were wired parallel, with 2 consequences:
1) it makes no difference which connector is used as input
2) the second cable (Fuji->Keyboard) acted as extension of the first cable (Ada->Fuji). And because they are twisted, twist+twist=straight. But the keyboard requires a twisted cable. Hence no signal or power to the keyboard.

After the rework, one of inputs remains for twisted input, and the other becomes a straight output (like Adam).
Even though V1.0 did not cause any damage switching 5V and signal for FujiNet or Keyboard, it may cause issues with other equipment, e.g. if its signal connected to ground.

So it would be extremely helpful to indicate the IN and OUT ports on the case

djtersteegc, 2024-01-03:
Yep, case was also updated with the v1.1 PCB commits.

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

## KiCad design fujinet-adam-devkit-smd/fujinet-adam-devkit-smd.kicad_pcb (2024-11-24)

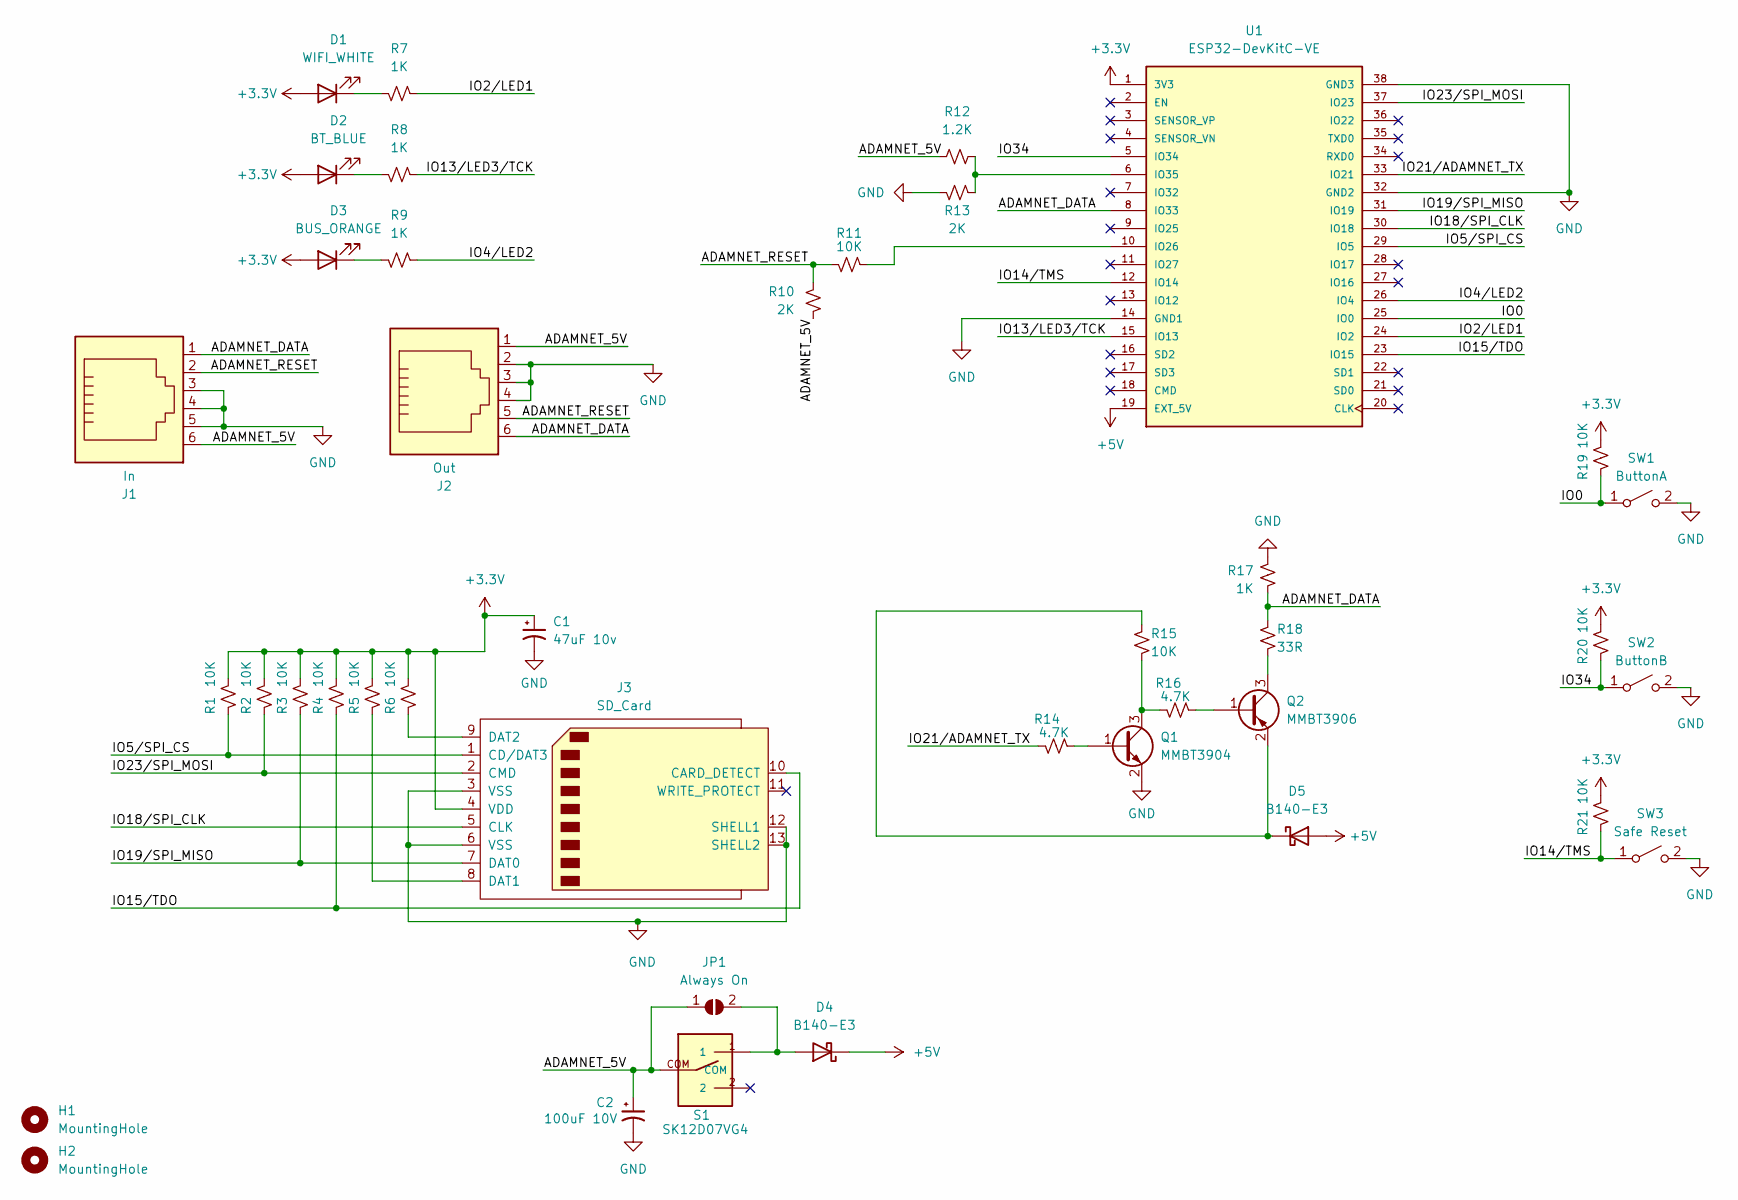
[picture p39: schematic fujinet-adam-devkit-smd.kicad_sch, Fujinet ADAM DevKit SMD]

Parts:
C1: 47uF 10v; CP_EIA-3528-15_AVX-H_Pad1.50x2.35mm_HandSolder
C2: 100uF 10V; CP_EIA-7343-20_Kemet-V_Pad2.25x2.55mm_HandSolder
D1: WIFI_WHITE; LED_D3.0mm
D2: BT_BLUE; LED_D3.0mm
D3: BUS_ORANGE; LED_D3.0mm
D4, D5: B140-E3; D_SMA
H1, H2: MountingHole; MountingHole_2.7mm_M2.5
J1: In; RJ12_Amphenol_54601
J2: Out; RJ12_Amphenol_54601
J3: SD_Card; SD_TE_2041021
JP1: Always On; SolderJumper-2_P1.3mm_Open_RoundedPad1.0x1.5mm
Q1: MMBT3904; SOT-23
Q2: MMBT3906; SOT-23
R1, R2, R3, R4, R5, R6, R11, R15, R19, R20, R21: 10K; R_0805_2012Metric_Pad1.20x1.40mm_HandSolder
R7, R8, R9, R17: 1K; R_0805_2012Metric_Pad1.20x1.40mm_HandSolder
R10, R13: 2K; R_0805_2012Metric_Pad1.20x1.40mm_HandSolder
R12: 1.2K; R_0805_2012Metric_Pad1.20x1.40mm_HandSolder
R14, R16: 4.7K; R_0805_2012Metric_Pad1.20x1.40mm_HandSolder
R18: 33R; R_0805_2012Metric_Pad1.20x1.40mm_HandSolder
S1: SK12D07VG4
SW1: ButtonA; SW_Push_SPST_NO_Alps_SKRK
SW2: ButtonB; SW_Push_SPST_NO_Alps_SKRK
SW3: Safe Reset; SW_Push_SPST_NO_Alps_SKRK
U1: ESP32-DevKitC-VE; MODULE_ESP32-DEVKITC-32U; PARTREV N/A

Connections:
+3.3V: C1.1, D1.2 (A), D2.2 (A), D3.2 (A), J3.4 (VDD), R1.2, R2.2, R3.2, R4.2, R5.2, R6.2, R19.2, R20.2, R21.2, U1.1 (3V3)
+5V: D4.1 (K), D5.2 (A), U1.19 (EXT_5V)
/ADAMNET_5V: C2.1, J1.6, J2.1, JP1.1 (A), R10.1, R12.1, S1.COM
/ADAMNET_DATA: J1.1, J2.6, R17.1, R18.2, U1.8 (IO33)
/ADAMNET_RESET: J1.2, J2.5, R10.2, R11.1
/IO0: R19.1, SW1.1 (A), U1.25 (IO0)
/IO2/LED1: R7.2, U1.24 (IO2)
/IO4/LED2: R9.2, U1.26 (IO4)
/IO5/SPI_CS: J3.1 (CD/DAT3), R1.1, U1.29 (IO5)
/IO13/LED3/TCK: R8.2, U1.15 (IO13)
/IO14/TMS: R21.1, SW3.1 (A), U1.12 (IO14)
/IO15/TDO: J3.10 (CARD_DETECT), R4.1, U1.23 (IO15)
/IO18/SPI_CLK: J3.5 (CLK), U1.30 (IO18)
/IO19/SPI_MISO: J3.7 (DAT0), R3.1, U1.31 (IO19)
/IO21/ADAMNET_TX: R14.2, U1.33 (IO21)
/IO23/SPI_MOSI: J3.2 (CMD), R2.1, U1.37 (IO23)
/IO34: R20.1, SW2.1 (A), U1.5 (IO34)
GND: C1.2, C2.2, J1.3, J1.4, J1.5, J2.2, J2.3, J2.4, J3.3 (VSS), J3.6 (VSS), J3.12 (SHELL1), J3.13 (SHELL2), Q1.2 (E), R13.1, R17.2, SW1.2 (B), SW2.2 (B), SW3.2 (B), U1.14 (GND1), U1.32 (GND2), U1.38 (GND3)
unnamed: D1.1 (K), R7.1
unnamed: D2.1 (K), R8.1
unnamed: D3.1 (K), R9.1
unnamed: D4.2 (A), JP1.2 (B), S1.1
unnamed: D5.1 (K), Q2.2 (E), R15.2
unnamed: J3.8 (DAT1), R5.1
unnamed: J3.9 (DAT2), R6.1
unnamed: Q1.1 (B), R14.1
unnamed: Q1.3 (C), R15.1, R16.2
unnamed: Q2.1 (B), R16.1
unnamed: Q2.3 (C), R18.1
unnamed: R11.2, U1.10 (IO26)
unnamed: R12.2, R13.2, U1.6 (IO35)

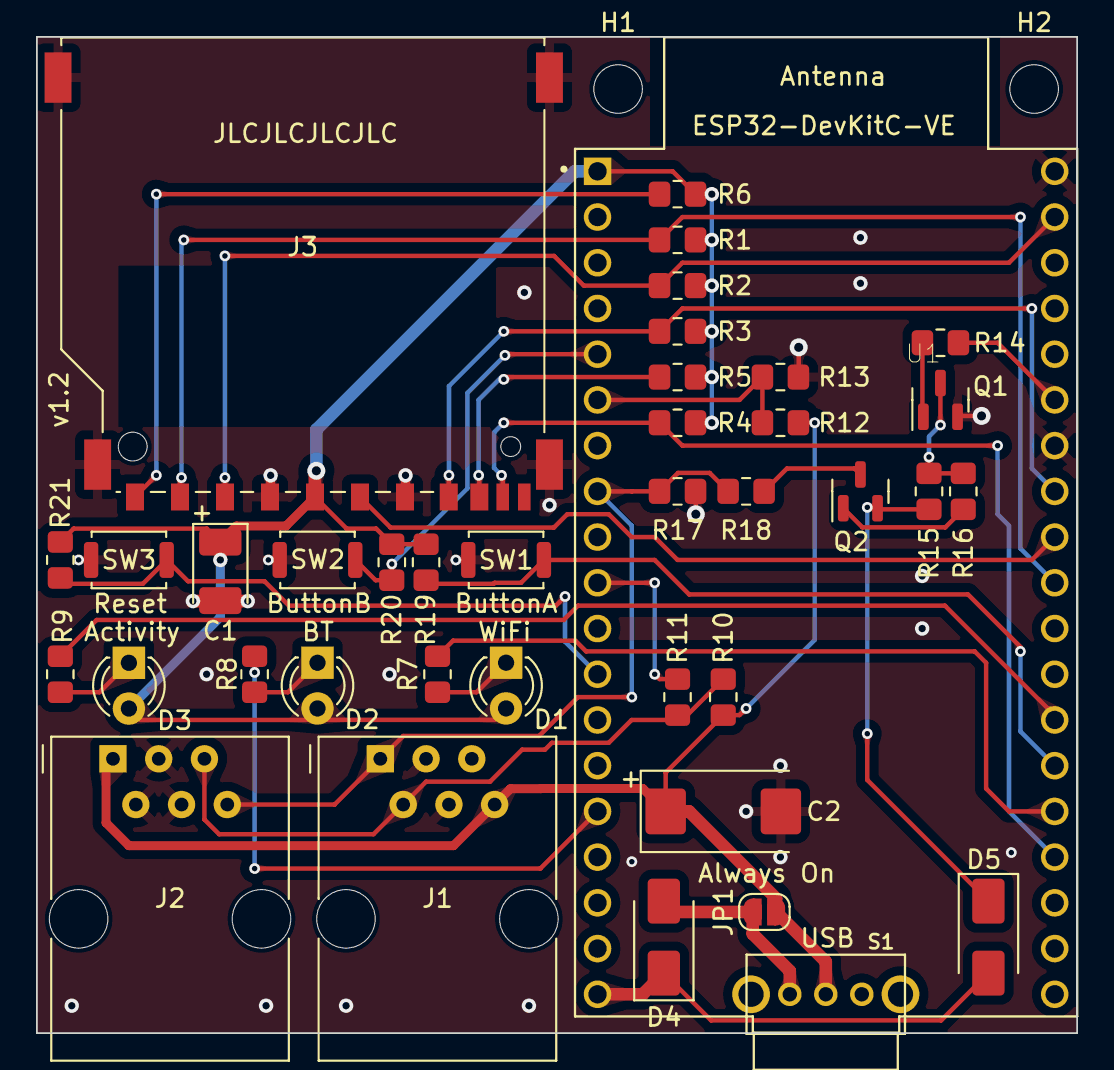
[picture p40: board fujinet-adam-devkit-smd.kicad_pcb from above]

Board: 2 copper layers, 57.8 x 55.3 mm, 41 parts (0 on the bottom side), 31 nets.

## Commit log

2023-11-11 Add some docs
    [fujinet-adam-devkit-mini-body.stl, fujinet-adam-devkit-mini-button.stl, fujinet-adam-devkit-mini-lid.stl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]
2023-11-11 Update docs
    [fujinet-adam-devkit-mini.csv, fujinet-adam-devkit-mini.kicad_pcb, fujinet-adam-devkit-mini.kicad_sch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]
2023-11-12 Fix Mini BOM in README
2023-12-25 Add rework cut pic
2023-12-26 Update SMD PCB and Case to v1.1, fix ADAMNet Out port not working
    [fujinet-adam-devkit-smd-B_Cu.gbr, fujinet-adam-devkit-smd-B_Mask.gbr, fujinet-adam-devkit-smd-B_Paste.gbr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]
2023-12-26 v1.1 PCB tweak
    [fujinet-adam-devkit-smd-B_Cu.gbr, fujinet-adam-devkit-smd-B_Mask.gbr, fujinet-adam-devkit-smd-B_Paste.gbr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]
2024-11-24 Add SMD version 1.2 PCB/case files and embossed text STL's for AMS printing
    [fujinet-adam-devkit-mini-body.stl, fujinet-adam-devkit-mini-embossed-text.stl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]
2026-01-02 Update SMD version to 1.3 Add tall case for versions with a power switch
